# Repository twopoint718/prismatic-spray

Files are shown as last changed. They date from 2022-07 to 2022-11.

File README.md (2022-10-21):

# Prismatic Spray 🌈

 

Designing a handheld RGB widget for light painting.
Named after the D&D spell by the same name.

<figure>
  <a href="https://forgottenrealms.fandom.com/wiki/Prismatic_spray">
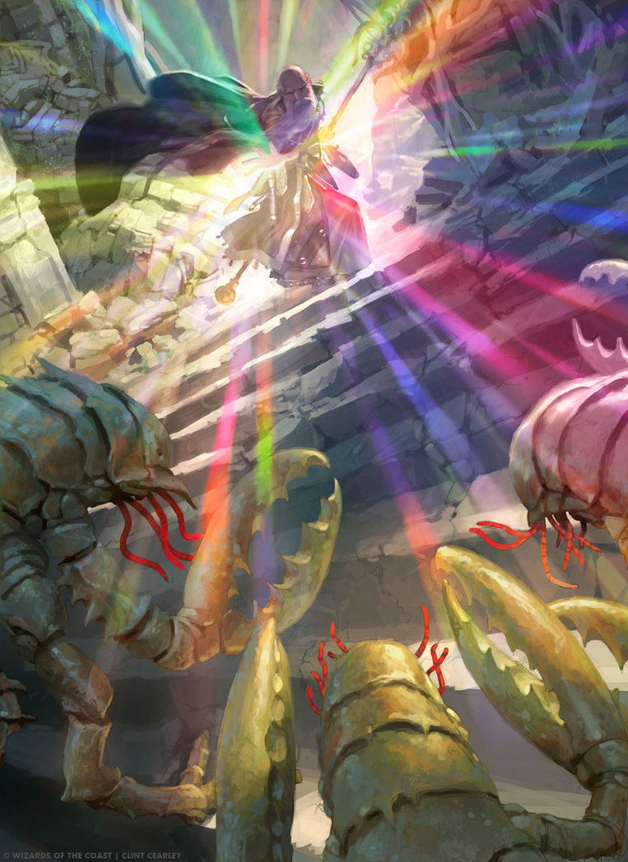
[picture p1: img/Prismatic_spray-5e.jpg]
Wizard casting the Prismatic Spray spell
    
  </a>
  <figcaption>A wizard casting the Prismatic Spray spell</figcaption>
</figure>

## Statechart

This [statechart](https://statecharts.dev/) gives an overview of the operation of Prismatic Spray:

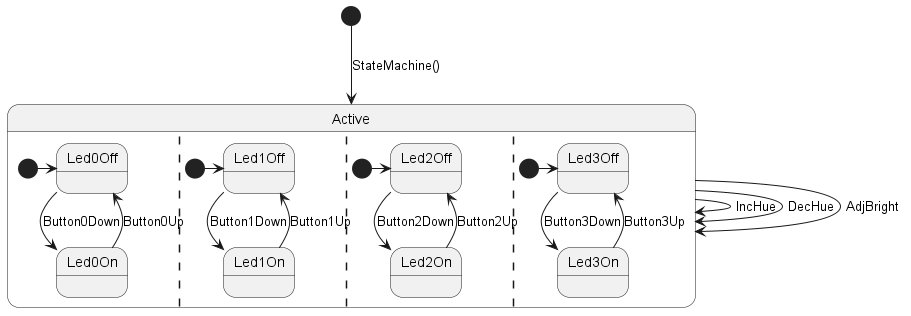
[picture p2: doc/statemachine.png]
Statechart diagram


When turned on, the device immediately transitions to the active state.
Conceptually, this initial transition can be seen as when the initialization code runs in the `StateMachine()` constructor.

In the Active state each of the concurrent sub-states for the 4 buttons are initially set
to "Led(N)Off". When a button is pressed down, the corresponding LED will illuminate until the button is released.
Pressing a button also has the side effect of setting the _focused_ LED.
This is the LED for which adjustments of the Hue knob or the Brightness knob will subsequently affect.
Only one LED can be focused like this and it will always be the last button pressed.
If no buttons have been pressed, it is `LED0`. 

The rotary encoder sets the hue/color of the focused LED in 24 equal steps.
These are spaced evenly around the HSL color wheel:

colorwheel

The brightness adjustment uses a potentiometer instead of a rotary encoder like hue.
This means that the brightness is set on an absolute scale from off to 100%.

## Prototype

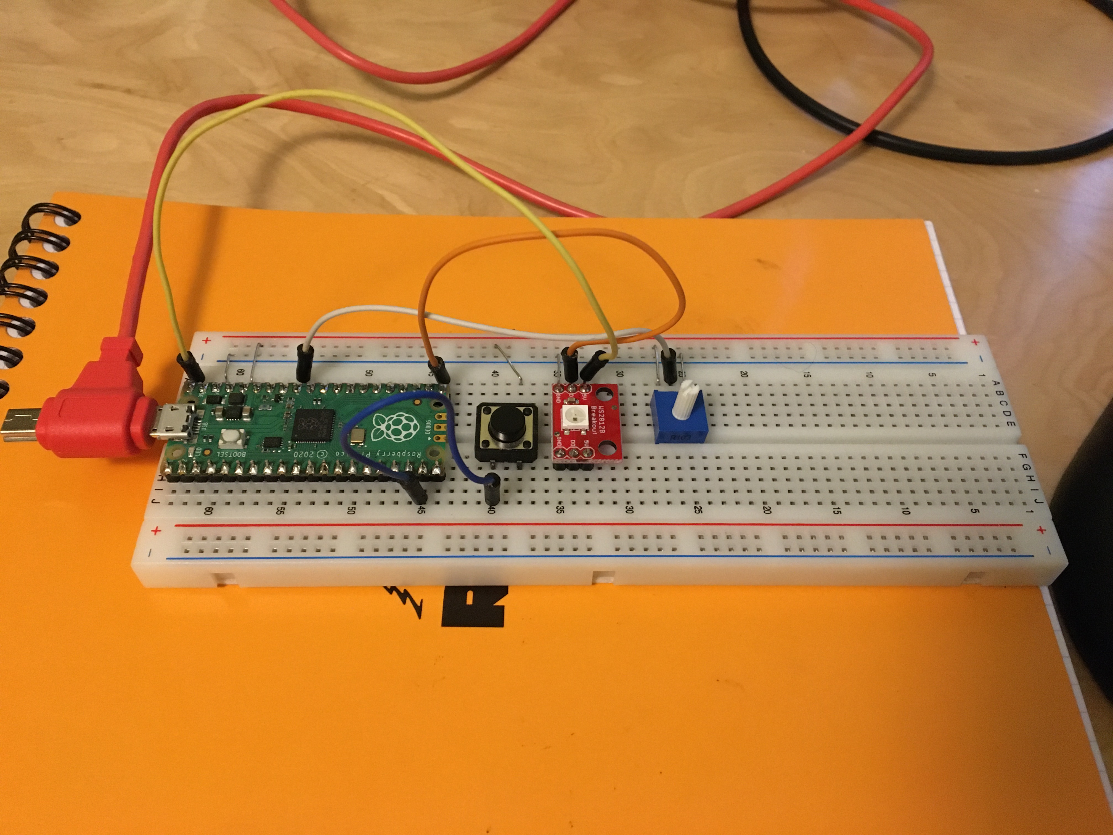
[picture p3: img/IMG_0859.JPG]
Prototype photo


Short video: https://twitter.com/twopoint718/status/1552858497666240512

## PCB

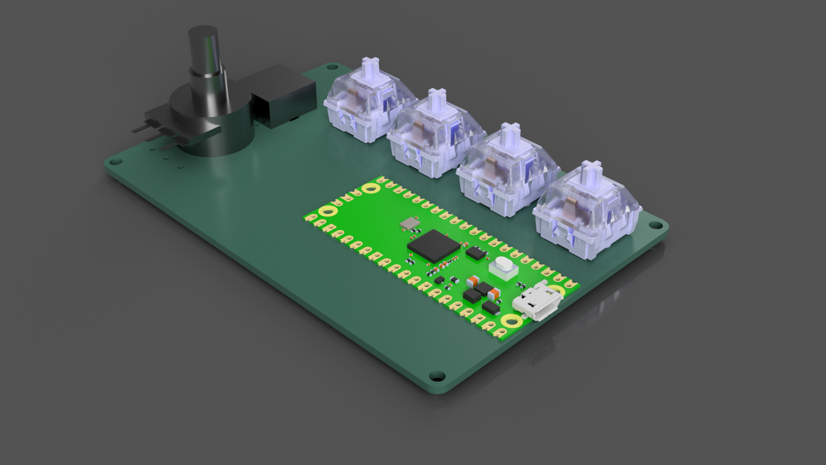
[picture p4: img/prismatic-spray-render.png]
PCB Rendering

- [x] split pcb into two files for main and daughter board
- [x] measure height of knobs for case lid clearance

## Resources/Parts Datasheets

- Cherry MX key switch https://gitlab.com/kicad/libraries/kicad-footprints/-/tree/master/Button_Switch_Keyboard.pretty
- Rotary encoder https://cdn-shop.adafruit.com/datasheets/pec11.pdf
  - Knob https://cdn-shop.adafruit.com/datasheets/EPD-200732.pdf
- Potentiometer https://cdn-shop.adafruit.com/datasheets/p160.pdf
  - Knob https://cdn-shop.adafruit.com/product-files/5541/knob+drawing.jpg
- Heat-set insert https://www.mcmaster.com/94180A321/

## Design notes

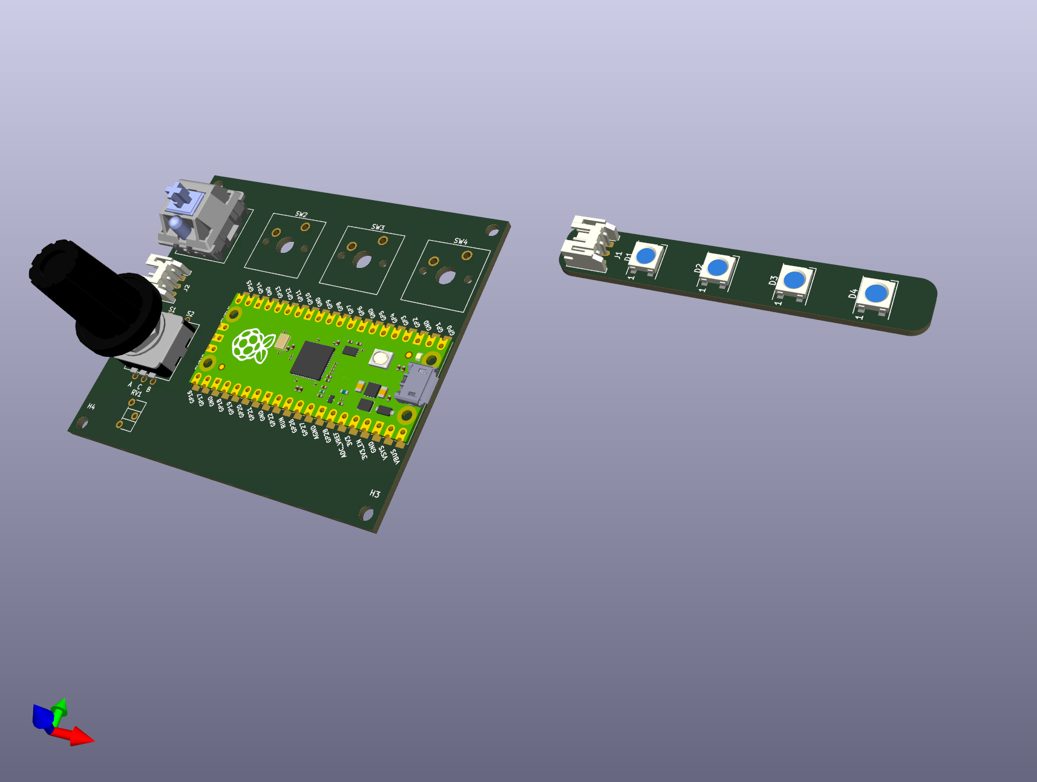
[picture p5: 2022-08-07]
img/prismatic-spray.png

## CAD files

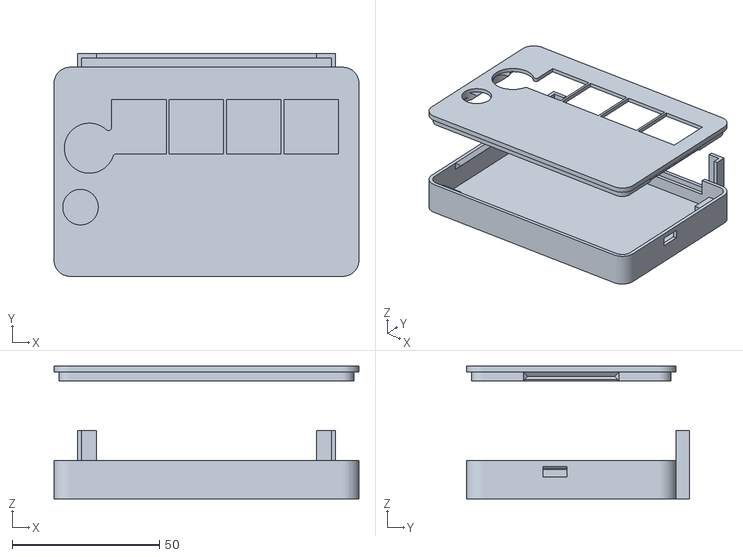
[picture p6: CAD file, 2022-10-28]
cad/case.stl
103.5 x 75.6 x 45.0

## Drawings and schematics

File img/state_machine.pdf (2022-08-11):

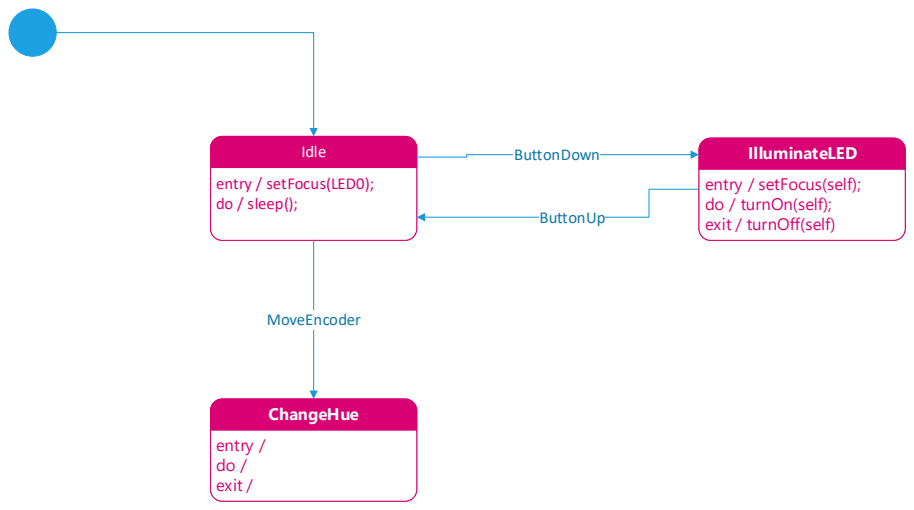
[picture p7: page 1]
Idle; entry / setFocus(LED0); do / sleep();; IlluminateLED; ButtonDown; ButtonUp; ChangeHue; entry / do / exit /; MoveEncoder

entry / setFocus(self);
do / turnOn(self);
exit / turnOff(self)

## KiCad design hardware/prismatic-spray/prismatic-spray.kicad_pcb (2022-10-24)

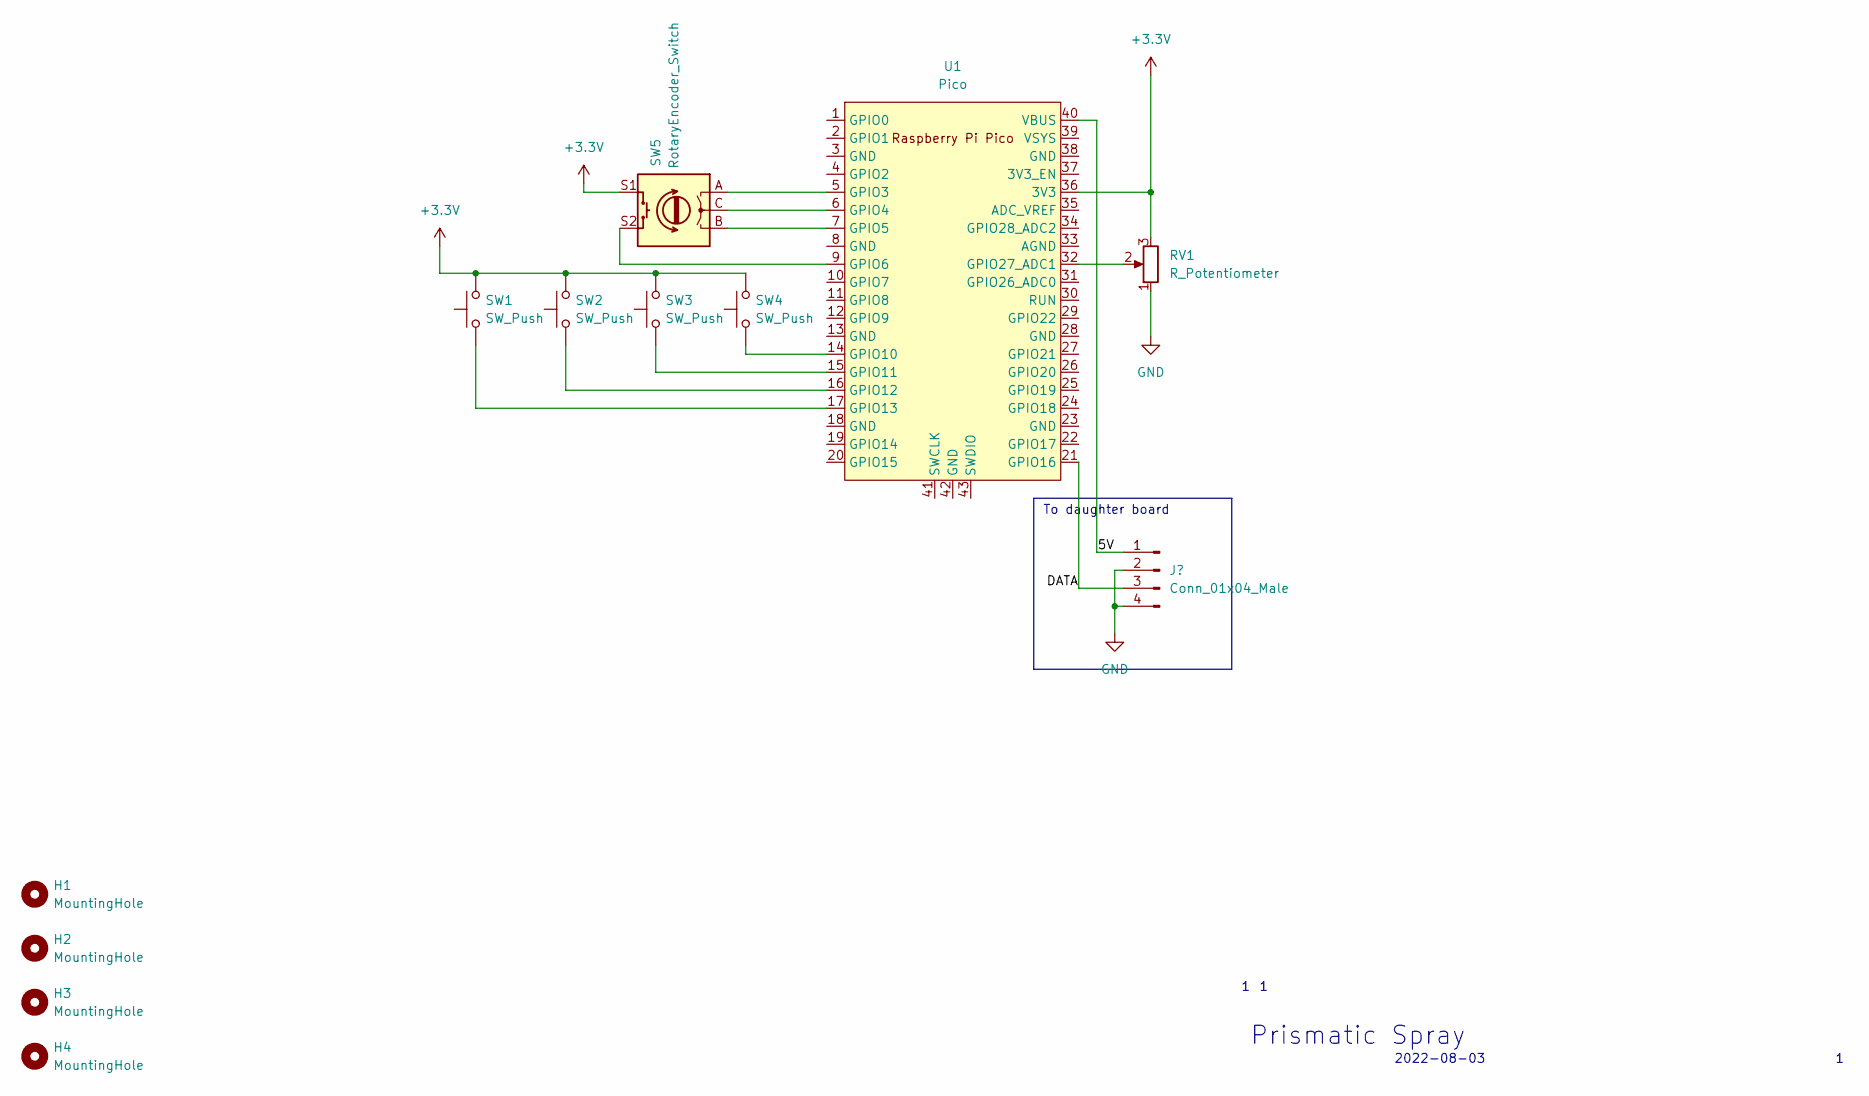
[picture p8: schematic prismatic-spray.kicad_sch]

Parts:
H1, H2, H3, H4: MountingHole; MountingHole_2.7mm_M2.5
RV1: R_Potentiometer; p160_potentiometer
SW1, SW2, SW3, SW4: SW_Push; SW_Cherry_MX_1.00u_PCB
SW5: RotaryEncoder_Switch; pec11_rotary_encoder
U1: Pico; RPi_Pico_SMD_TH

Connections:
+3V3: RV1.3, SW1.2, SW2.2, SW3.2, SW4.2, SW5.S1, U1.36 (3V3)
/5V_A: U1.40 (VBUS); also elsewhere on the board
/DATA_A: U1.21 (GPIO16); also elsewhere on the board
GND: RV1.1; also elsewhere on the board
unnamed: RV1.2, U1.32 (GPIO27_ADC1)
unnamed: SW1.1, U1.17 (GPIO13)
unnamed: SW2.1, U1.16 (GPIO12)
unnamed: SW3.1, U1.15 (GPIO11)
unnamed: SW4.1, U1.14 (GPIO10)
unnamed: SW5.A, U1.5 (GPIO3)
unnamed: SW5.C, U1.6 (GPIO4)
unnamed: SW5.B, U1.7 (GPIO5)
unnamed: SW5.S2, U1.9 (GPIO6)

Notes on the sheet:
To daughter board
2022-08-03
Prismatic Spray

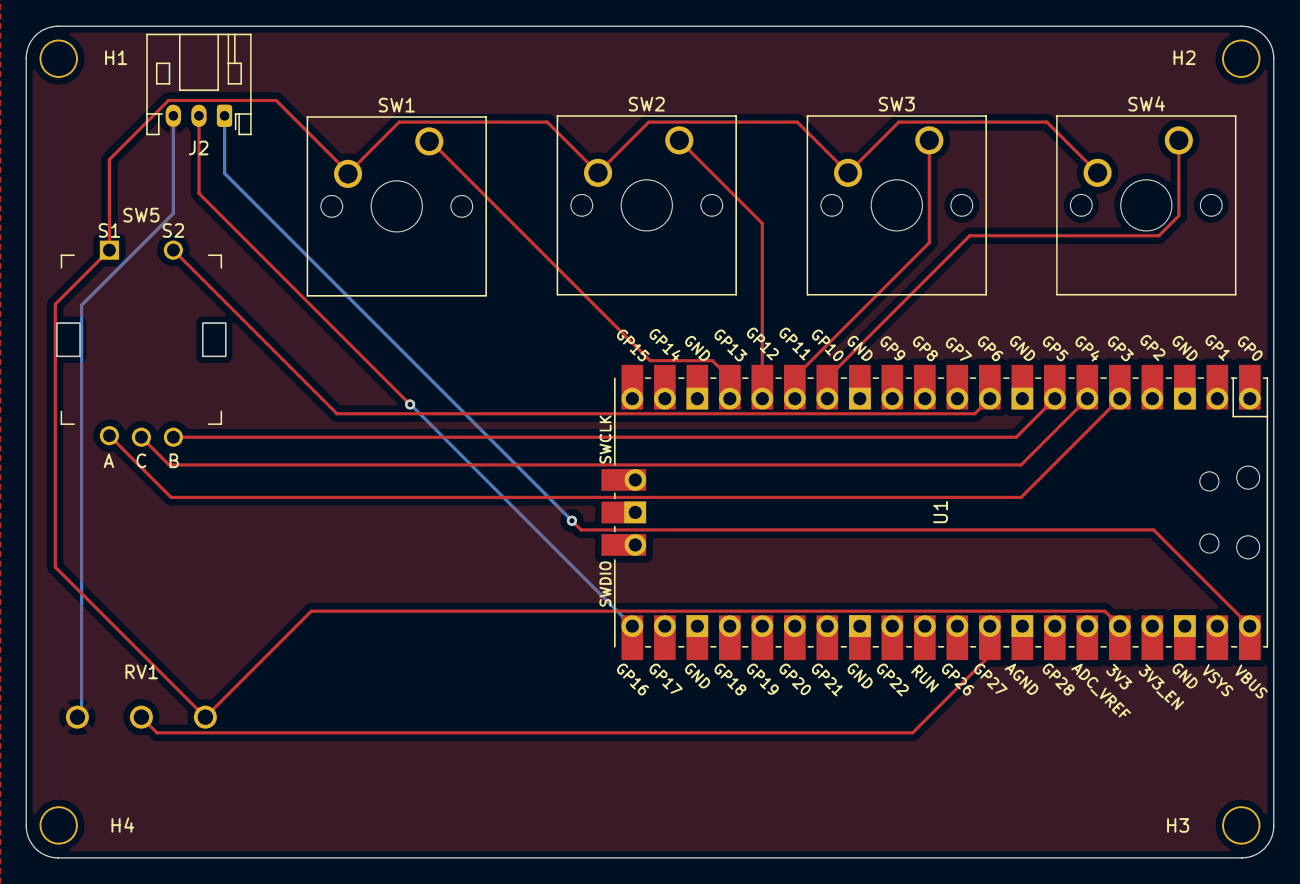
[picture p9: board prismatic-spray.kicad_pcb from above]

Board: 2 copper layers, 97.5 x 65.0 mm, 12 parts (0 on the bottom side), 13 nets.

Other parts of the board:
J2: Conn_01x03_Male; JST_PH_S3B-PH-K_1x03_P2.00mm_Horizontal

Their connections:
/5V_A: J2.1; also elsewhere on the board
/DATA_A: J2.2; also elsewhere on the board
GND: J2.3; also elsewhere on the board

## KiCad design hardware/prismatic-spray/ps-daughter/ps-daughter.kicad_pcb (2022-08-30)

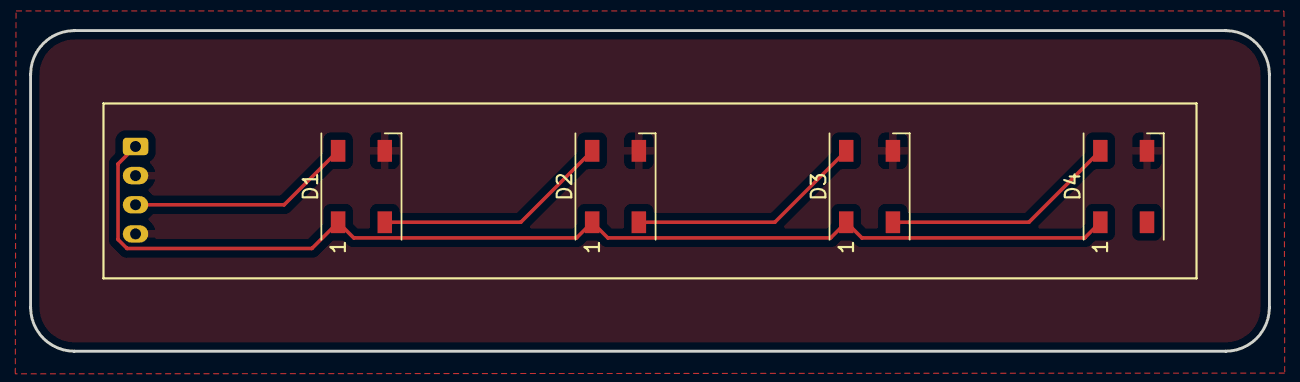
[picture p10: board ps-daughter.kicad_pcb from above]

Board: 2 copper layers, 85.0 x 22.0 mm, 5 parts (1 on the bottom side), 6 nets.

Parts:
D1, D2, D3, D4: WS2812B; LED_WS2812B_PLCC4_5.0x5.0mm_P3.2mm
J1: Conn_01x04_Male; JST_PH_S4B-PH-K_1x04_P2.00mm_Horizontal

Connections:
+5V: D1.1 (VDD), D2.1 (VDD), D3.1 (VDD), D4.1 (VDD), J1.1
GND: D1.3 (VSS), D2.3 (VSS), D3.3 (VSS), D4.3 (VSS), J1.2, J1.4
unnamed: D1.2 (DOUT), D2.4 (DIN)
unnamed: D1.4 (DIN), J1.3
unnamed: D2.2 (DOUT), D3.4 (DIN)
unnamed: D3.2 (DOUT), D4.4 (DIN)

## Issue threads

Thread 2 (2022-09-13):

State machine outputs “commands”

twopoint718, 2022-09-13:
Gist of a working version: https://gist.github.com/twopoint718/f3a3dfc5fe36419f1475602194acb9eb

`Cmd`s allow state machinery to be pure (ie not depend on BSP) and instead return a tuple of an action-enum along with the next state (if any).

cf. https://guide.elm-lang.org/effects/

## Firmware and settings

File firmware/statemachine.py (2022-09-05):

# Events to be handled
class Event:
    def __init__(self, value):
        self.value = value

class AdjustBrightness(Event): pass
class ButtonDown(Event): pass
class ButtonUp(Event): pass
class IncrementHue(Event): pass
class DecrementHue(Event): pass

class StateMachine:
    def __init__(self, bsp):
        # Extended state variables
        self.curr_pixel = 0
        self.curr_brightness = 1.0
        self.pixels = [0, 0, 0, 0]

        # State machine internal variables
        self.__state = None
        self.__bsp = bsp

        self.transition(self.idle_state)

    def get_state(self):
        return self.__state

    def get_focus(self):
        return self.pixels[self.curr_pixel]

    def set_focus(self, n):
        self.pixels[self.curr_pixel] = n

    def inc_focus(self):
        n = self.get_focus() + 1
        if n > 23:
            self.set_focus(0)
        else:
            self.set_focus(n)

    def dec_focus(self):
        n = self.get_focus() - 1
        if n < 0:
            self.set_focus(23)
        else:
            self.set_focus(n)

    def dispatch(self, event: Event):
        """Send the incoming event to the current state. The event subclass will
        have any arguments expected by that handler."""
        self.__state(event)

    def transition(self, newState):
        self.__state = newState

################################################################################
## STATES

    def idle_state(self, event: Event):
        if type(event) == IncrementHue:
            self.curr_pixel = event.value
            self.inc_focus()
        elif type(event) == DecrementHue:
            self.curr_pixel = event.value
            self.dec_focus() 
        elif type(event) == ButtonDown:
            self.curr_pixel = event.value
            self.__bsp.led_on(self.curr_pixel, self.pixels[self.curr_pixel])
            self.transition(self.led_on_state)
        else:
            # TODO: testing only?
            raise NotImplementedError()

    def led_on_state(self, event: Event):
        if type(event) == ButtonUp:
            self.curr_pixel = event.value
            self.__bsp.led_off(self.curr_pixel)
            self.transition(self.idle_state)

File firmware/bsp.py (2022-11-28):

# 24 precomputed hues as RGB. Each value is 15 degrees (360/24) separated in
# degrees of hue. These values can be passed directly to the neopixel fill func. 
HUES = [
    (255, 0, 0),   (255, 63, 0),  (255, 127, 0), (255, 191, 0),
    (255, 255, 0), (191, 255, 0), (127, 255, 0), (63, 255, 0),
    (0, 255, 0),   (0, 255, 63),  (0, 255, 127), (0, 255, 191),
    (0, 255, 255), (0, 191, 255), (0, 127, 255), (0, 63, 255),
    (0, 0, 255),   (63, 0, 255),  (127, 0, 255), (191, 0, 255),
    (255, 0, 255), (255, 0, 191), (255, 0, 127), (255, 0, 63)
]
NUM_HUES = 24

class BSP:
    def __init__(self, neopixel, machine):
        # Buttons
        self.button0 = machine.Pin(14, machine.Pin.IN, machine.Pin.PULL_DOWN)
        # self.button1 = Pin(??, Pin.IN, Pin.PULL_DOWN) 
        # self.button2 = Pin(??, Pin.IN, Pin.PULL_DOWN) 
        # self.button3 = Pin(??, Pin.IN, Pin.PULL_DOWN) 

        # Pin: 32, ADC1, GP27
        # self.hueInput = ADC(Pin(27))

        # Pin: 25, on-board LED
        self.onboard_led = machine.Pin(25, machine.Pin.OUT)

        # NeoPixel (WS2812)
        self.num_pixels = 4
        # Pin: 21, GP16
        machine.Pin(16, machine.Pin.OUT)
        self.pixel = neopixel.NeoPixel(machine.Pin(16), self.num_pixels)
        
    def led_on(self, n, hue, brightness=1):
        self.pixel[n].fill(HUES[hue])
        self.pixel[n].write()

    def led_off(self, n):
        self.pixel[n].fill((0,0,0))
        self.pixel[n].write()

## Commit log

2022-07-28 Add prototype Circuit Python code
2022-07-29 Add potentiometer to set color (hue)
    - LED turns on when button is pressed
2022-07-29 Add prototype photo and link to video
2022-08-01 Add 3d file for case design
    [case.stl]
2022-08-04 Add KiCAD files
    [prismatic-spray.kicad_pcb, prismatic-spray.kicad_sch]
2022-08-05 Add 4th button and LED
    Also add a rotary encoder for color control (pot is for brightness)
    [prismatic-spray.kicad_sch]
2022-08-06 Add mounting holes
    - Add non-plated mounting holes
    - Reposition board
    - Place potentiometer
    - TODO: rotary encoder
    [prismatic-spray.kicad_pcb, prismatic-spray.kicad_sch]
2022-08-07 Populate board with more footprints/3d models
    - Add Cherry MX key switch 3d model
    - Add PEC11 rotary encoder 3d model
    - Add Raspberry Pi Pico 3d model
    - Add PEC11 footprint (from schematic)
    - Change rotary encoder schematic symbol to 3 encoder pins + 2 switch pins
    - Add PCB rendering for docs
    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
    [prismatic-spray.kicad_pcb, prismatic-spray.kicad_sch]
2022-08-09 Add P160 Potentiometer
    - Add custom footprint
    - TODO: add outline/screenprint for PCB size
    [prismatic-spray.kicad_pcb, prismatic-spray.kicad_sch]
2022-08-10 Route most traces
    - Route most traces on main board and daughter board
    - Add mounting holes to daughter board
    - Flip daughterboard connector to back of PCB
    - Reassign some GPIOs for better routing
    - Fix footprint for pec11 to get clean DRC
    [prismatic-spray.kicad_pcb, prismatic-spray.kicad_sch]
2022-08-10 Add dimentions to PCB
    [prismatic-spray.kicad_pcb]
2022-08-16 Separate boards into different schematics
    KiCAD: 1 board = 1 project
    So sayeth the forums:
    https://forum.kicad.info/t/hooking-up-a-separate-board-to-the-main-one-with-a-cable/37093
    [prismatic-spray.kicad_sch, ps-daughter.kicad_pcb, ps-daughter.kicad_sch]
2022-08-30 PCB Rev 1
    Hardware rev 1
    - Main board
    - Daughter board
    [prismatic-spray.kicad_pcb, ps-daughter.kicad_pcb]
2022-09-07 Use concurrent states ↔️
2022-09-27 Add rendered image
    [prismatic-spray.kicad_pcb]
2022-09-28 Update case (WIP)
    Case WIP
    - modeling the main board and daughter board for fit
    - bottom portion of the case is good, working on the top and connecting the two
    [case.stl]
2022-10-21 WIP: Update case design
    WIP: Redesign case using the ideas of this video for a
    snap-together lid: https://youtu.be/VVmOtM60VWw
    [case.stl]
2022-10-23 Punch holes in the case lid for buttons & knob
    [case.stl]
2022-10-24 finished case
    [case.stl, prismatic-spray.kicad_pcb]
2022-10-25 v1 of case
    I think the STL file is essentially complete.
    [case.stl]
2022-10-28 Revise CAD based on measurements
    After printing the first version, took some measurements and moved the side charging USB port
    [case.stl]

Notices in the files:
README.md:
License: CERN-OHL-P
